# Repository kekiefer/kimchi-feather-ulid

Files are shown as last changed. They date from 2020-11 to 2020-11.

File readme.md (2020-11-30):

# kimχ micro lid KiCad project template

This template lets you create lid expansion boards for the [kimχ micro i.MX8M Mini SBC](https://labs.groupgets.com/kimchi-micro).

This project should include everything you need to make an expansion board, including an eeprom
that can be used to identify your lid and automatically load the correct configuration files (with
some software work to support this).

## How to use this project

This project is to be used with KiCad's "New Project from Template" function.

### Download with GitHub

On GitHub you can select Clone or Download -> Download Zip, and save into your KiCad templates directory. The user template directory is $HOME/kicad/template/

In KiCad, select File > New Project > New Project From Template, and select User Templates. You can then select the kimχ micro - LID project in this list.

### Clone with GitHub

Alternatively, you can create a new GitHub project from this template by selecting Use This Template, above. From there you clone the new project locally and open it directly with KiCad.

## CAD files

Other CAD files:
case.FCStd

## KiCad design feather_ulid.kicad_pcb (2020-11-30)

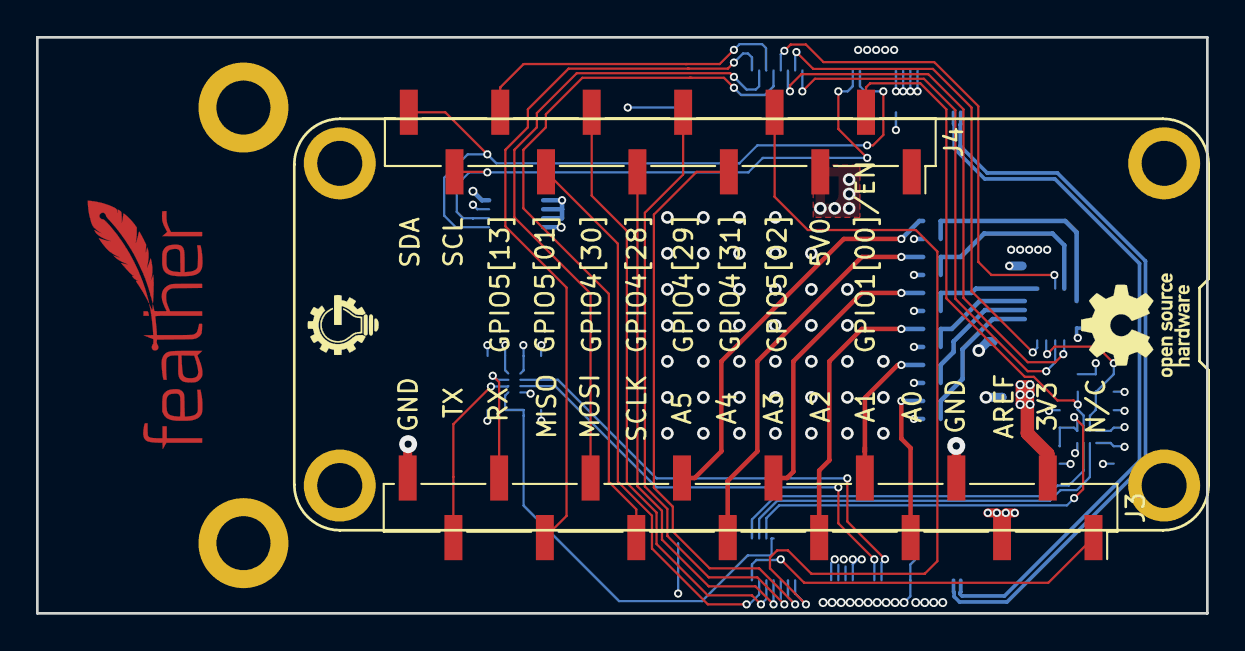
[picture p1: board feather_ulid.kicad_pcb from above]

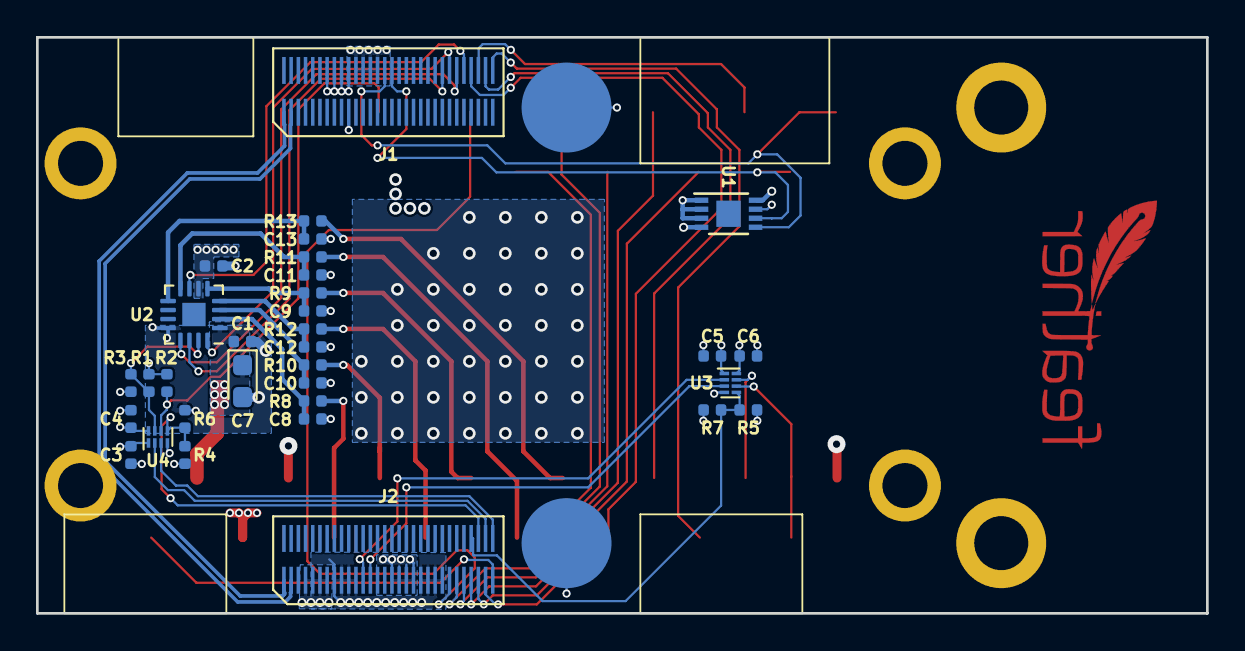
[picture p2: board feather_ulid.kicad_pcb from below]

Board: 4 copper layers, 65.0 x 32.0 mm, 45 parts (34 on the bottom side), 46 nets.

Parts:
C1, C2, C3, C4, C5, C6: 0.1uF; C_0402_1005Metric
C7: CP_Small; CP_EIA-2012-15_AVX-P
C8, C9, C10, C11, C12, C13: 680pF 1%; C_0402_1005Metric
FID1: Fiducial; Untitled
H1, H2, H3, H4: MountingHole_Pad; MountingHole_3mm_Pad
H5, H6, H7, H8: MountingHole_Pad; MountingHole_2.5mm_Pad
J1, J2: DF40HC(3.5)-60DS
J3: Conn_Left; PinHeader_1x16_P2.54mm_Vertical_SMD_Pin1Right
J4: Conn_Right; PinHeader_1x12_P2.54mm_Vertical_SMD_Pin1Right
L1: GG_LOGO; gg-4x4
LOGO1: Logo_Open_Hardware_Small; OSHW-Logo_5.7x6mm_SilkScreen
R1, R2, R3, R4, R5, R6, R7: 100K; R_0402_1005Metric
R8, R9, R10, R11, R12, R13: 12K 1%; R_0402_1005Metric
U1: 24C32; DFN-8-1EP_3x2mm_P0.5mm_EP1.36x1.46mm
U2: AD5592R; LFCSP-16-1EP_3x3mm_P0.5mm_EP1.3x1.3mm
U3, U4: TXS0102DQE; X2SON-8_1.4x1mm_P0.35mm

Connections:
/A0: J3.5, R8.2
/A0_F: C8.1, R8.1, U2.2
/A1: J3.6, R10.2
/A1_F: C10.1, R10.1, U2.3
/A2: J3.7, R12.2
/A2_F: C12.1, R12.1, U2.4
/A3: J3.8, R9.2
/A3_F: C9.1, R9.1, U2.5
/A4: J3.9, R11.2
/A4_F: C11.1, R11.1, U2.8
/A5: J3.10, R13.2
/A5_F: C13.1, R13.1, U2.9
/Aref: C2.1, J3.3, U2.6
/EN: J4.2, R2.2, U4.6
/GPIO1[1]_HV: R1.2, R3.1, U2.15, U4.7
/RX: J3.14, U3.7
/TX: J3.15, U3.6
ECSPI1_MISO: J1.26, U2.7
ECSPI1_MOSI: J1.25, U2.13
ECSPI1_SCLK: J1.23, U2.14
ECSPI1_SS0: J1.24, U2.16
ECSPI2_MISO: J1.30, J3.13
ECSPI2_MOSI: J1.29, J3.12
ECSPI2_SCLK: J1.27, J3.11
ECSPI2_SS0: J1.28, J4.10
GND: C1.1, C2.2, C3.2, C4.2, C5.2, C6.2, C7.2, C8.2, C9.2, C10.2, C11.2, C12.2, C13.2, H1.1, H2.1, H3.1, H4.1, H5.1, H6.1, H7.1, J1.11, J1.12, J1.13, J1.14, J1.51, J2.38, J2.39, J2.40, J2.41, J2.50, J2.51, J2.52, J2.53, J3.4, J3.16, R3.2, R6.2, R7.2, U1.4, U1.7, U2.12, U3.4, U4.4
GPIO1[0]: J2.30, U4.3
GPIO1[1]: J2.29, U4.2
GPIO1[9]: J2.28, R4.2, R6.1, U4.5
GPIO1[10]: J2.27, R5.2, R7.1, U3.5
I2C4_SCL: J1.16, J4.11, U1.6
I2C4_SDA: J1.15, J4.12, U1.5
PCIE_USB_D_N: J1.59, J2.60
PCIE_USB_D_P: J1.60, J2.59
SAI3_MCLK: J2.37, J4.4
SAI3_RXC: J2.35, J4.6
SAI3_RXD: J2.33, J4.8
SAI3_RXFS: J2.34, J4.7
SAI3_TXC: J2.31, J3.1
SAI3_TXD: J2.32, J4.9
SAI3_TXFS: J2.36, J4.5
UART3_RX: J2.49, U3.2
UART3_TX: J2.48, U3.3
VDD_1V8: C3.1, C5.1, J2.42, J2.43, J2.44, J2.45, R4.1, R5.1, U3.1, U4.1
VDD_3V3: C1.2, C4.1, C6.1, C7.1, J2.54, J2.55, J2.56, J2.57, J3.2, R1.1, R2.1, U1.1, U1.2, U1.3, U1.8, U2.1, U3.8, U4.8
VDD_5V: J1.7, J1.8, J1.9, J1.10, J4.3
